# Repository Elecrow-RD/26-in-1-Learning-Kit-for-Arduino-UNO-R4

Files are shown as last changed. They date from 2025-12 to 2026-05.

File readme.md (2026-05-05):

## Menu
### 1, Product picture
### 2, Product version number
### 3, product information
### 4, Use the driver module
### 5,Quick Start
### 6,Folder structure.
### 7,Pin definition

### 1, Product picture

Crowpanel Advance ESP32 HMI AI Display

#### 2, Product version number

| | Hardware | Software | Remark |
| ---- | --- | --- | --- |
| 1 | V1.0 | V1.0 | latest |
### 3, product information

| Main Processor | Arduino UNO R4 |
| --- | --- |
| CPU/SoC | RA4M1(Arm® Cortex-M4®) |
| System memory | 32 kB SRAM |
| Storage | 256 kB Flash Memory |
| Bluetooth | Bluetooth 5 |
| Wi-Fi | Wi-Fi® support with 802.11 b/g/n standarBit rate at up to 150 Mbps2.4 GHz band |
| Interface | 6\*D Interfaces<br />4\*A Interfaces<br />4\*I2C Interfaces<br />4\* Pin header<br />2\*3pin connectors<br />1*Stepper Interface |
| Button | Reset |
| LED indicator light | 12*8 LED dot matrix |
| Power input | 5 V |
| Shell material | Plastic Box |
| Size | 278\*200*43（mm） |
| Net Weight | 600g |
| Operating temperature | 0°C to 60°C |
| Storage temperature | 0°C to 60°C |

### 4, Use the driver module

| Name | dependency library |
| --- | --- |
| IRremote | Arduino-IRremote-master <br />version: 4.5.0 |
| LSM6DS3  | Arduino_LSM6DS3-master<br />version=1.0.3 |
| BH1750 | BH1750<br />version: 1.3.0 |

### 5,Quick Start
### Arduino IDE starts

1.Download the library files used by this product to the 'libraries' folder.

C:\Users\Documents\Arduino\libraries\



2.Open the Arduino IDE and install the Uno development board.

Arduino_UNO_R4-2

3.Open the code configuration environment and burn it

Arduino_UNO_R4-4

### 6,Folder structure.

|--Eagle_SCH&PCB: Contains **Eagle CAD** schematic (`.sch`) and PCB layout (`.brd`) files. These are used for circuit design and PCB manufacturing.

|--Single Module Example:Examples of individual modules.

|--lesson_code: Provides  code and projects to demonstrate how to use the hardware and libraries. These examples help users get started quickly.

|--libraries: Includes necessary libraries required for compiling and running the project. These libraries provide drivers and additional functionalities for the hardware.

### 7,Pin definition

uno r4

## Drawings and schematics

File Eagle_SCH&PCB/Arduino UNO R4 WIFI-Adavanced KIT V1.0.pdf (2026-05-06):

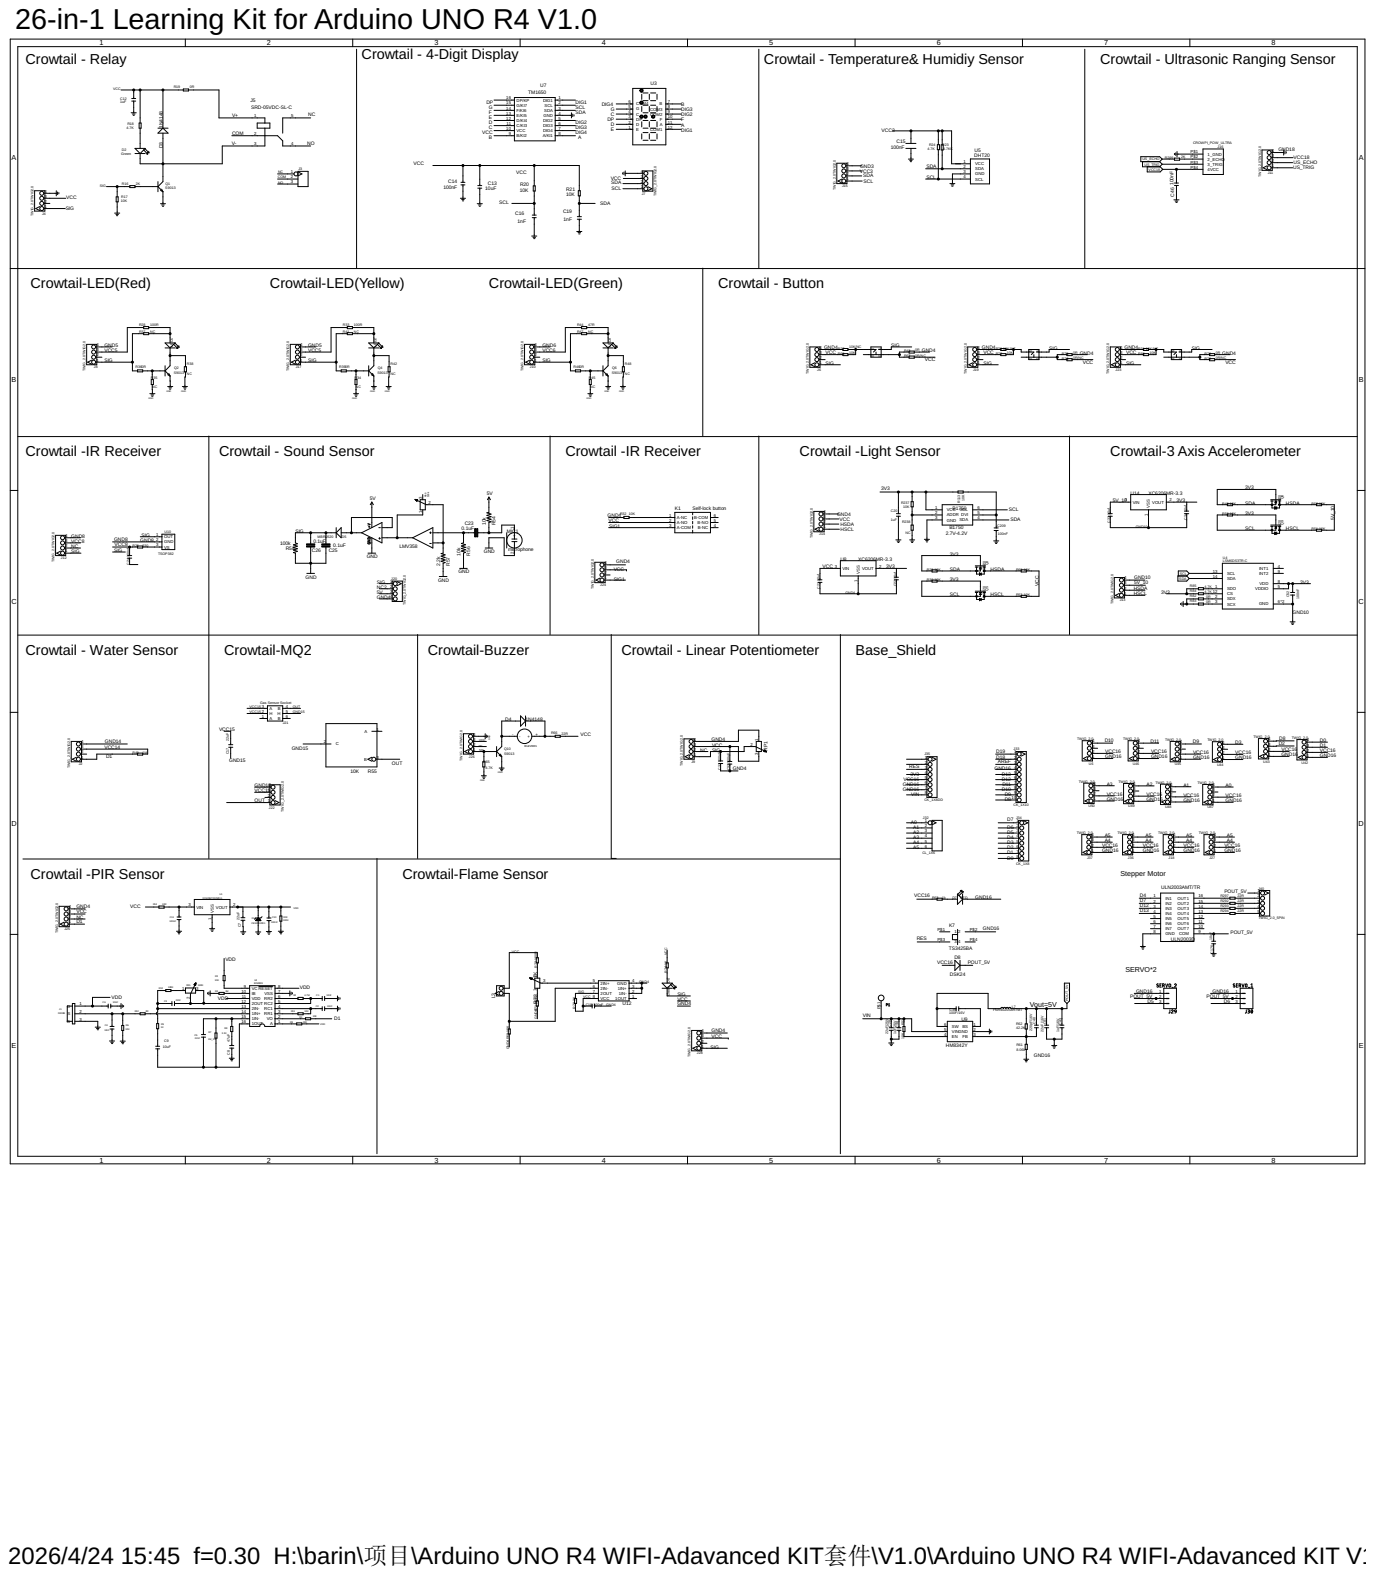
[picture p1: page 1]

Crowtail - Temperature& Humidiy Sensor

2026/4/24 15:45 f=0.30 H:\barin\项目\Arduino UNO R4 WIFI-Adavanced KIT套件\V1.0\Arduino UNO R4 WIFI-Adavanced KIT V1.0.sch (Sheet: 1/1)

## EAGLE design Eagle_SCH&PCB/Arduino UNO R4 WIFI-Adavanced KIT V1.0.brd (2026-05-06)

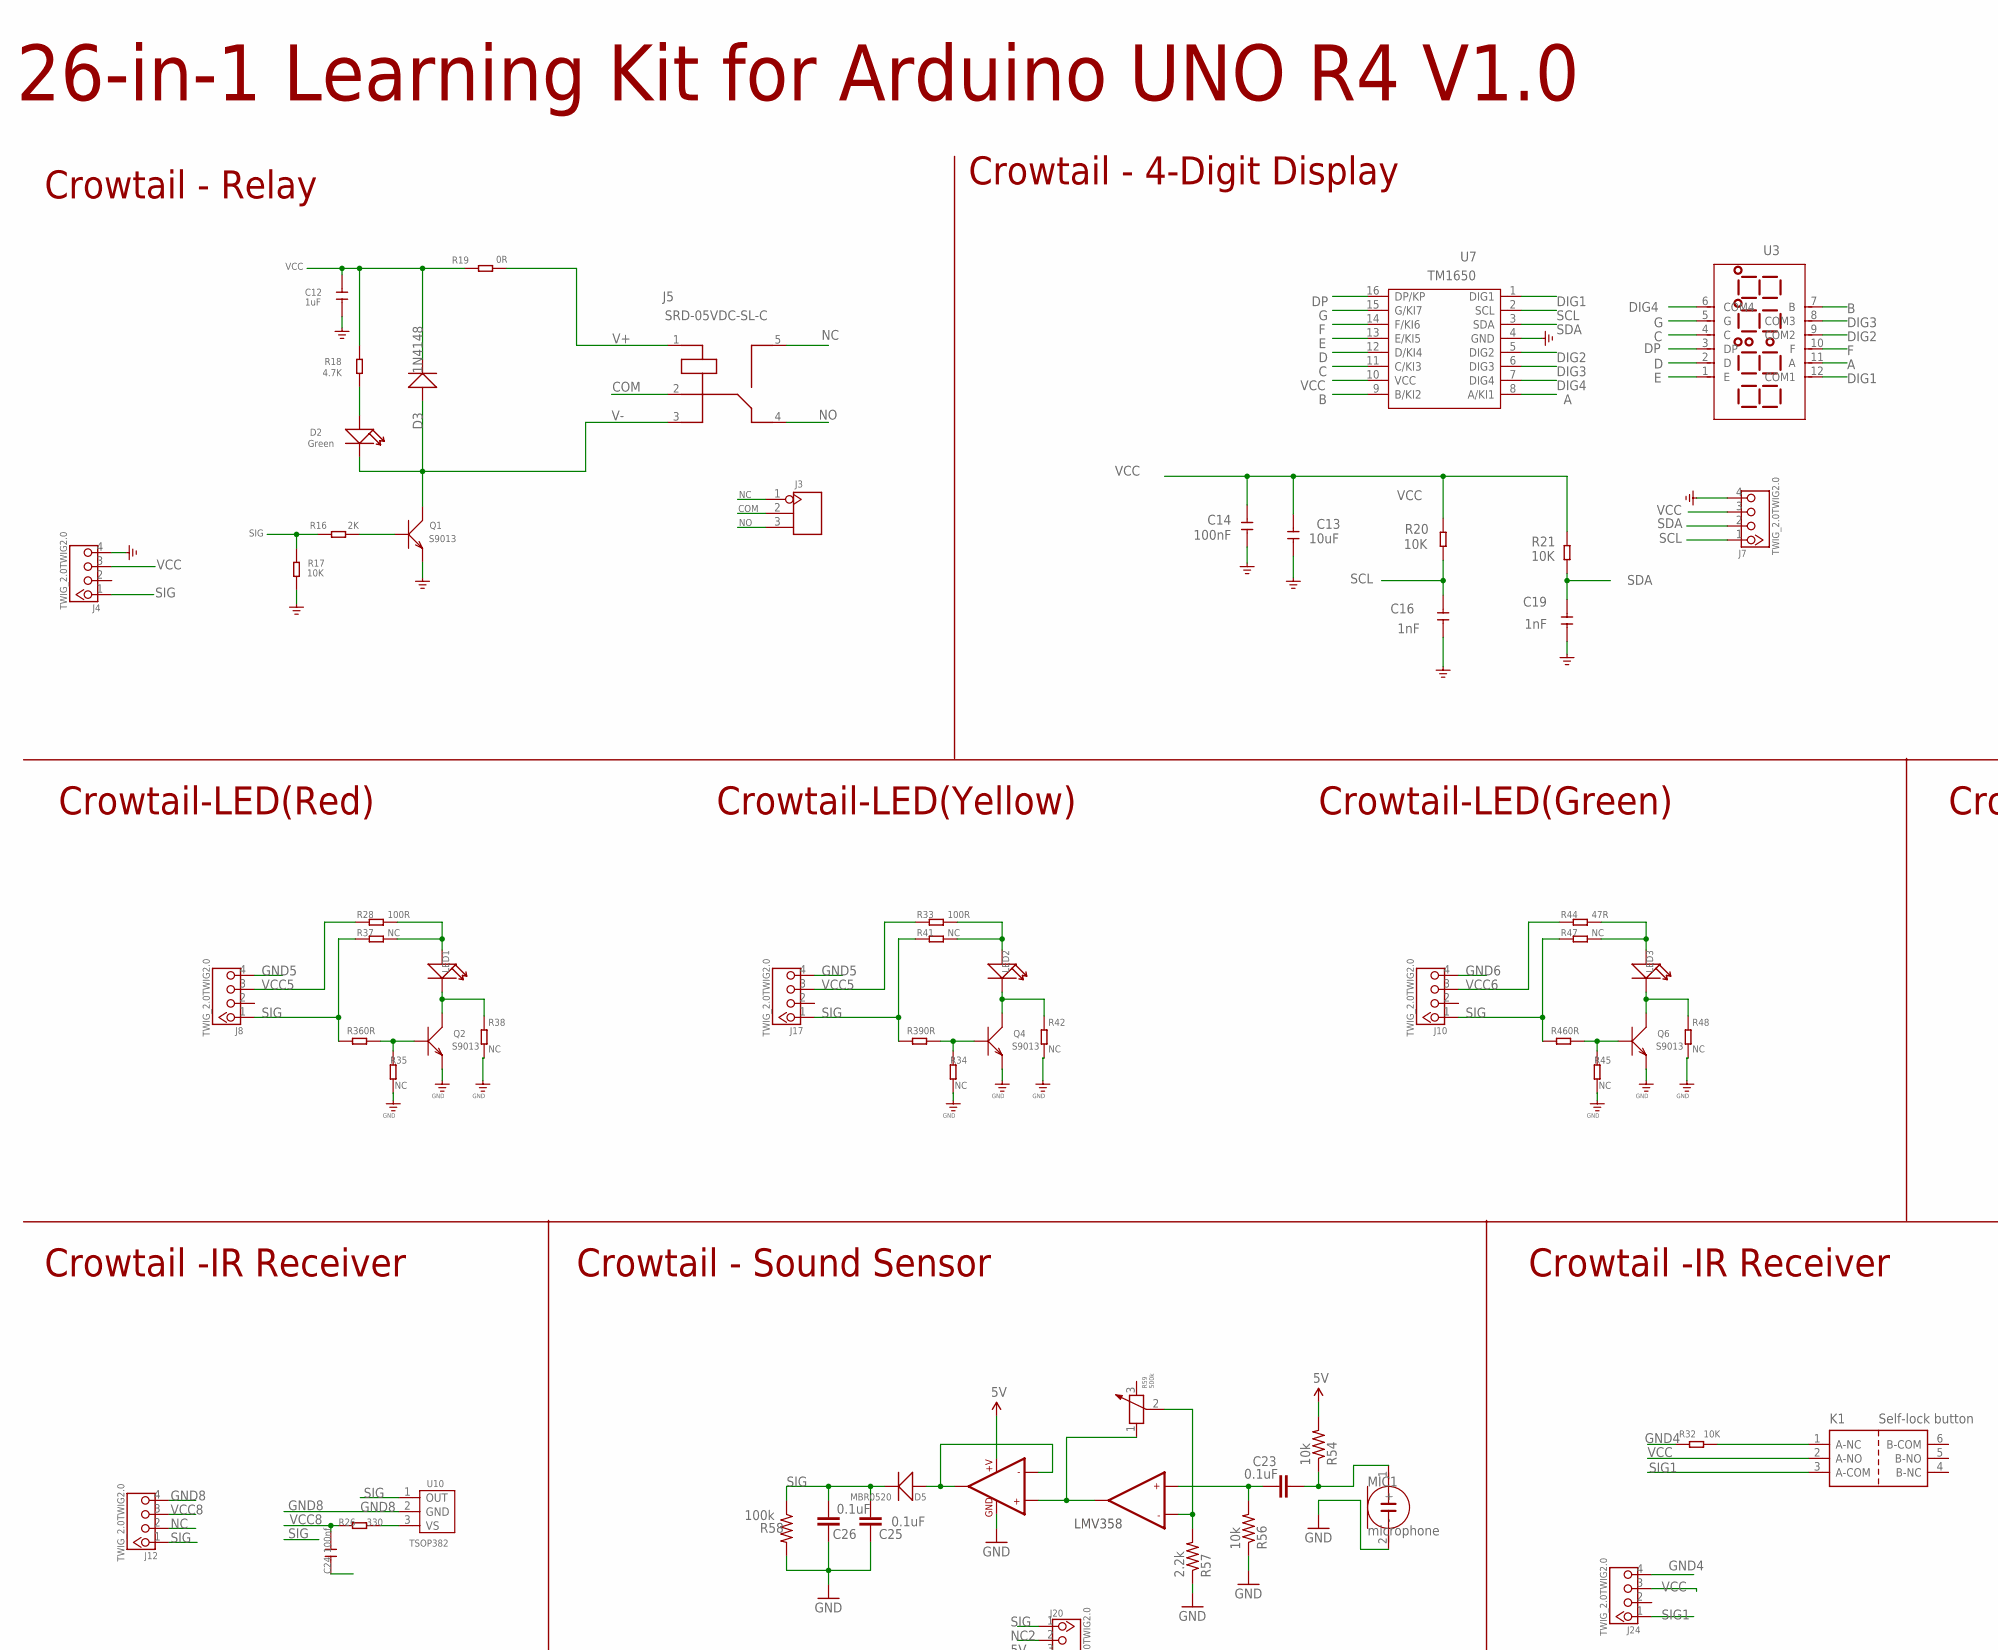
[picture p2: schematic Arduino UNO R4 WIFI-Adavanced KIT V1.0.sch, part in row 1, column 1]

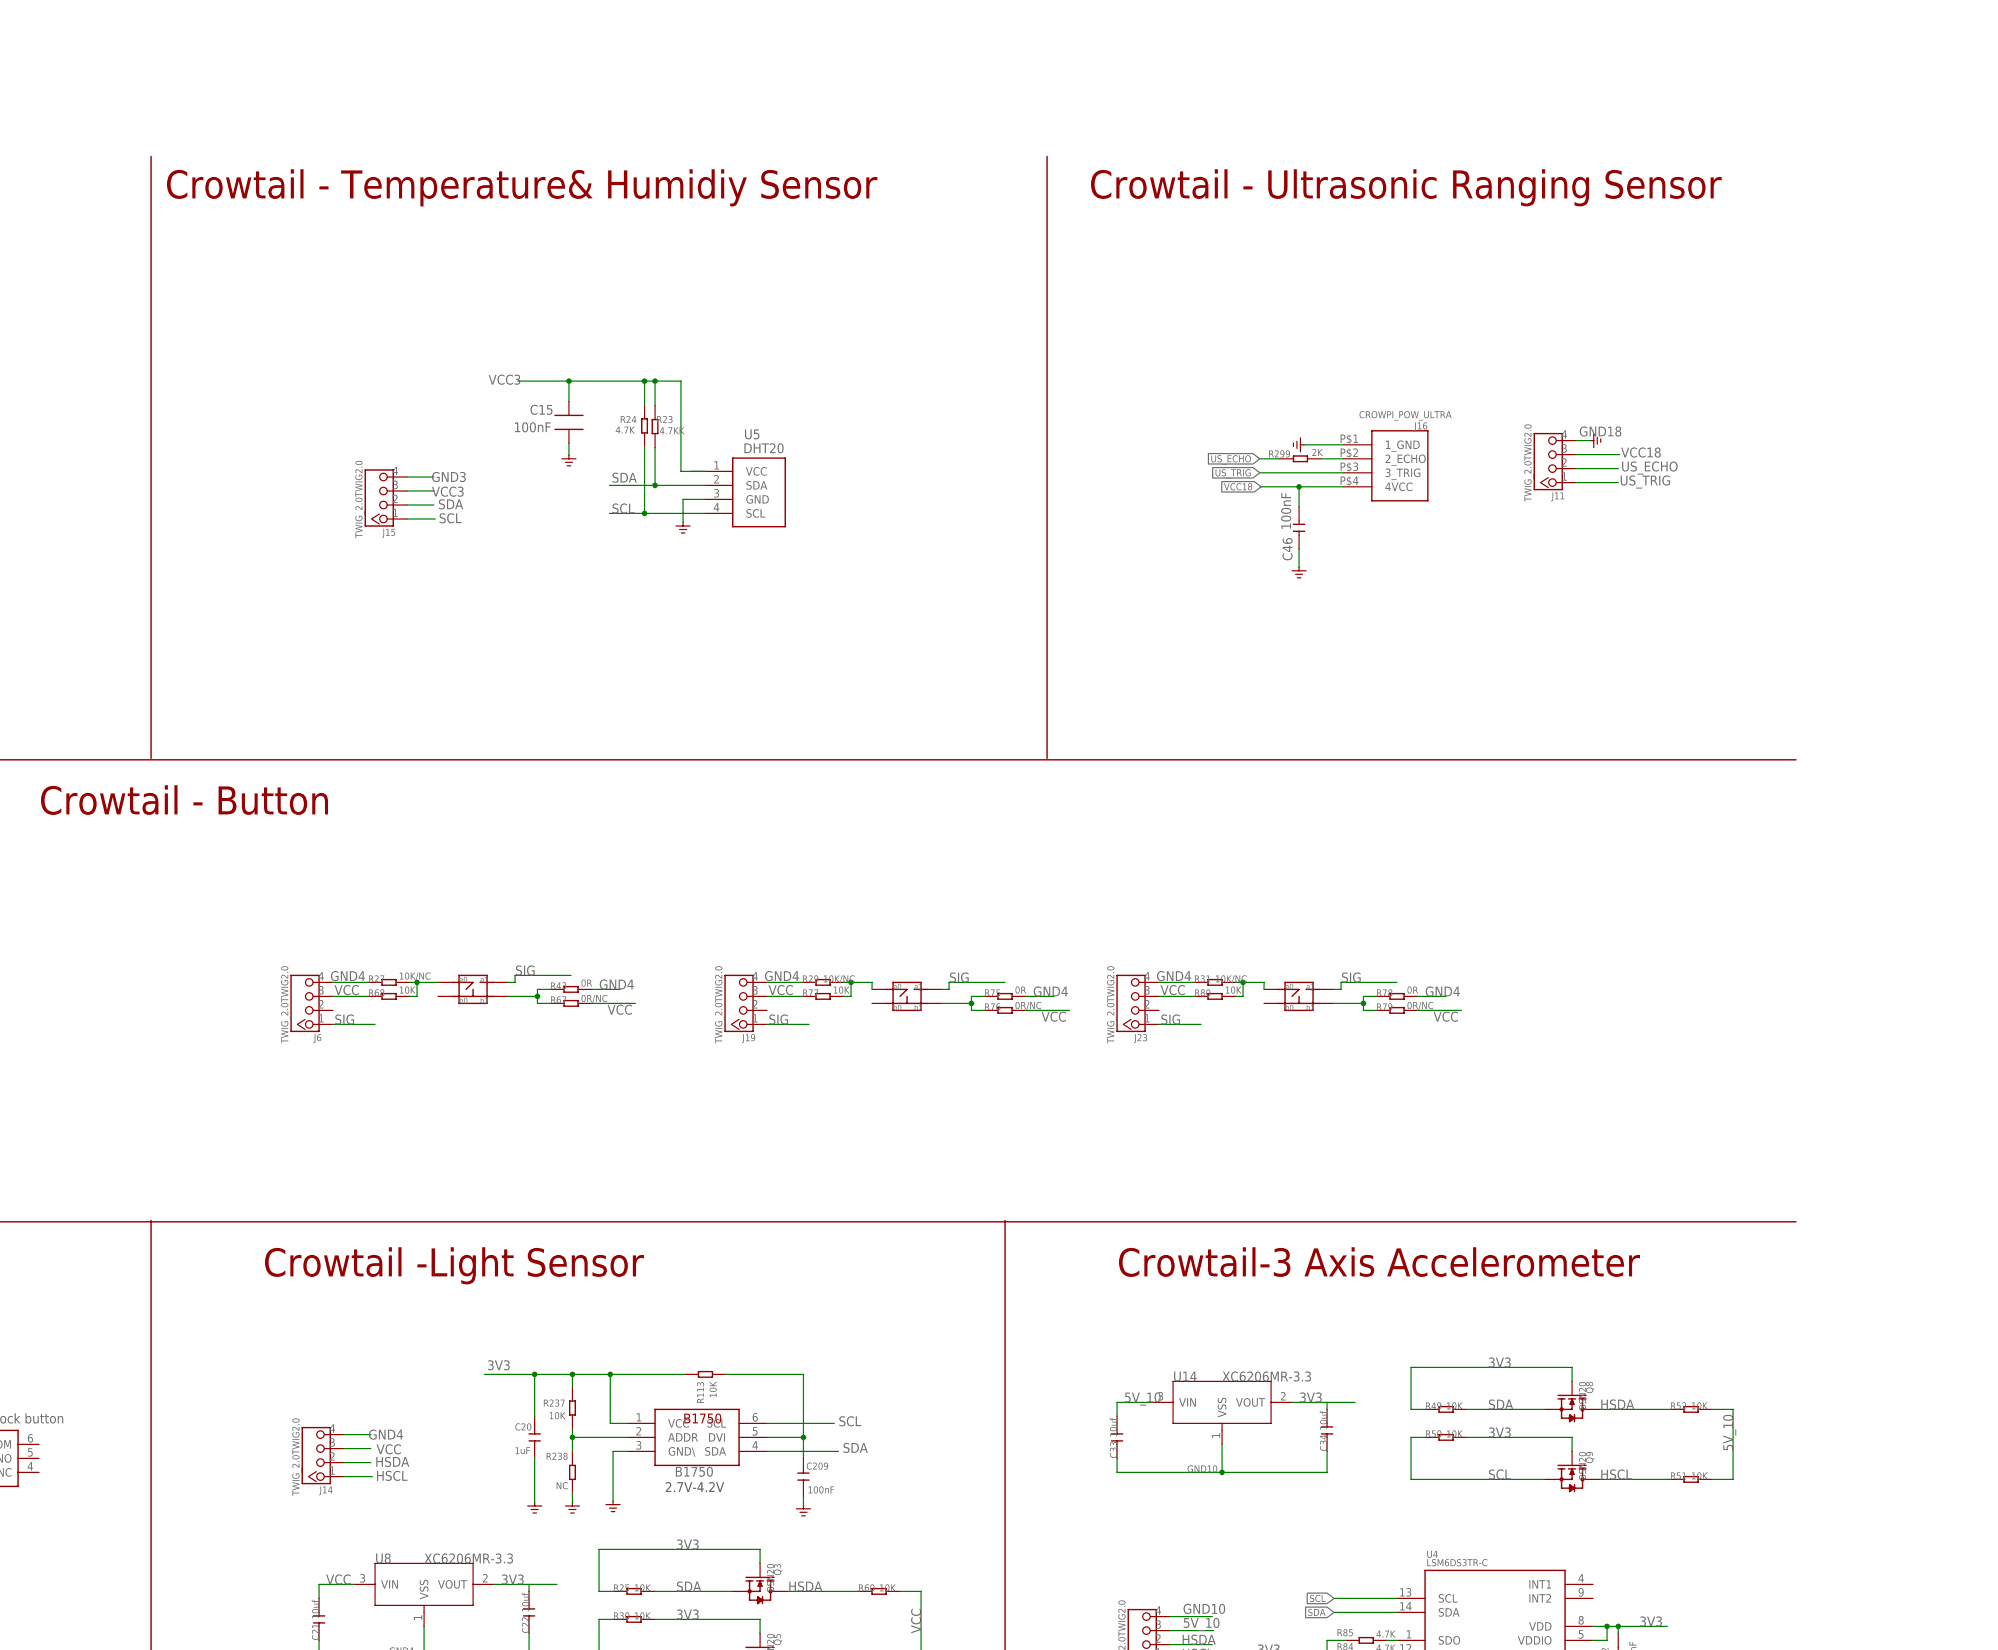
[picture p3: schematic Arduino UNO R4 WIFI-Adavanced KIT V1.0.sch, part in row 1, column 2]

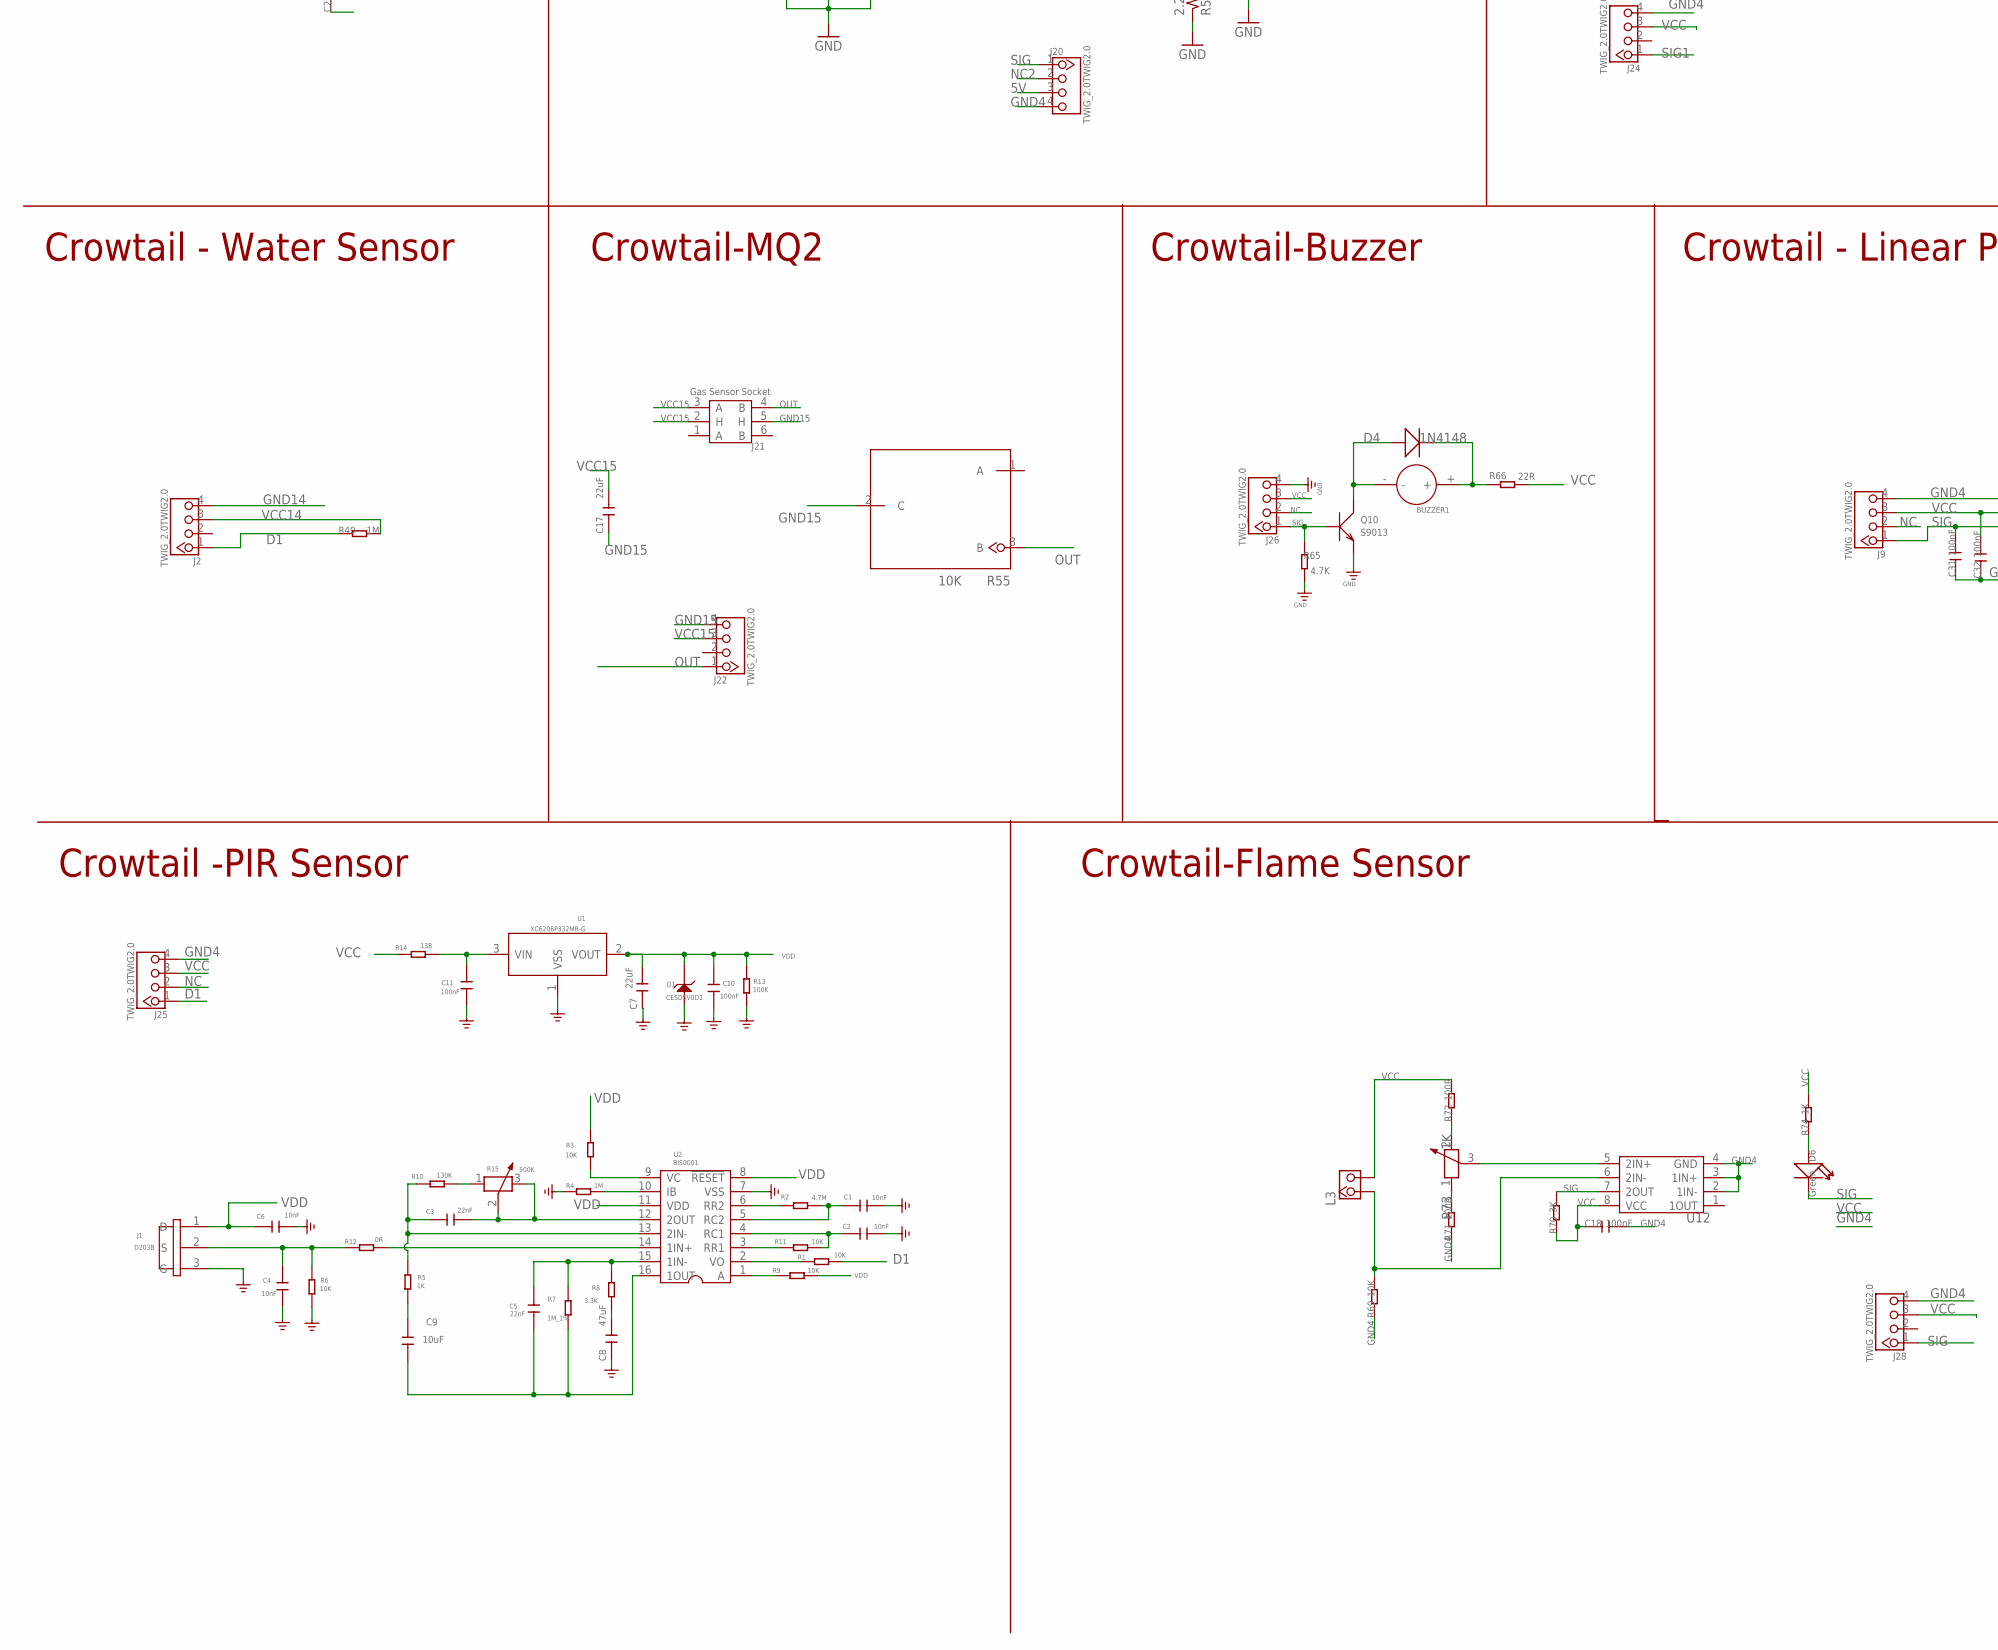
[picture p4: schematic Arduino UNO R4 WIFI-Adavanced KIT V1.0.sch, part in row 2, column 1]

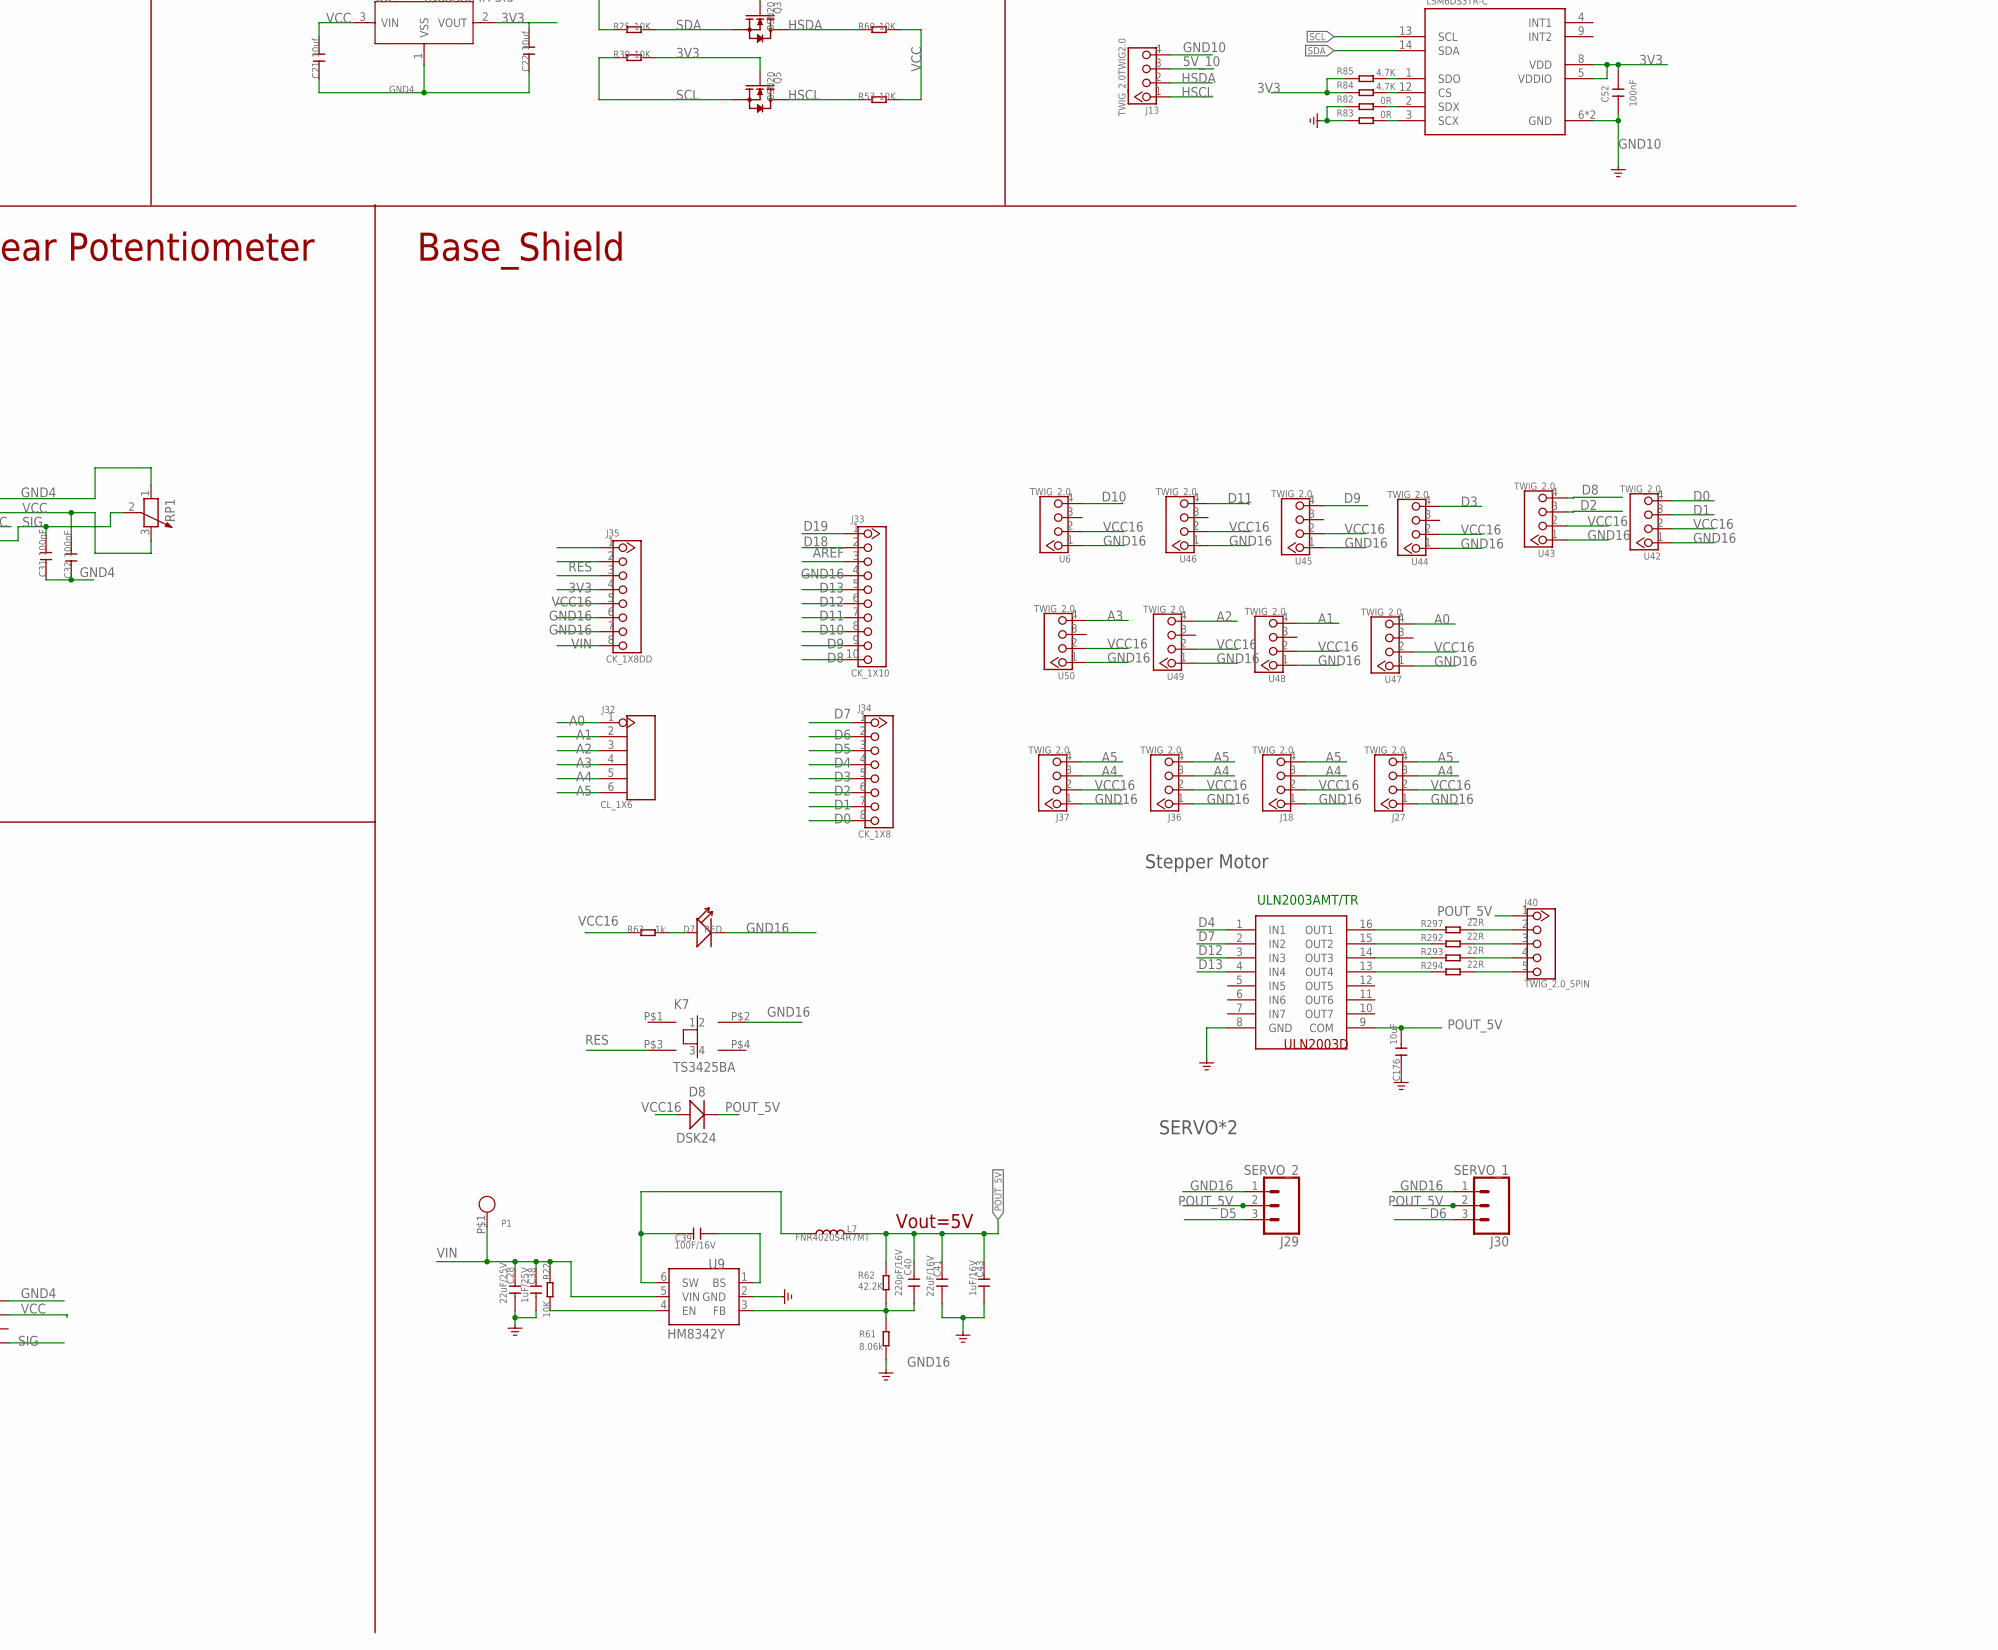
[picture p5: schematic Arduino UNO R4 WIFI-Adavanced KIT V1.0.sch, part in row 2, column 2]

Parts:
BUZZER1: BUZZER-YMD12065; 2P-7.6-D12X6.5H
C1, C2, C4, C6: 10nF; C0603
C3, C5: 22nF; C0603
C7, C17: 22uF; C0805
C8: 47uF; C0805
C9: 10uF; 0603
C10, C11, C14, C18, C31, C32, C46, C52, C209: 100nF; C0603
C12: 1uF; 0603
C13: 10uF; C0603
C15: 100nF; 0603
C16, C19: 1nF; C0603
C20: 1uF; C0603
C21, C22, C33, C34: 10uf; C0603
C23, C25, C26: 0.1uF; 0603-CAP
C24: 100nf; C0603
C28: 22uF/25V; C0805
C38: 1uF/25V; C0603
C39: 100F/16V; C0402
C40: 220pF/16V; C0402
C41: 22uF/16V; C0603
C43: 1uF/16V; C0603
C176: 10uF; C0805
D1: CESD5V0D1; SOD123-2.7X1.6@1
D2, D6: Green; LED-0603
D3, D4: 1N4148; D_SOD123
D5: MBR0520; SOD123-2.7X1.6
D7: RED; LED-0805
D8: DSK24; D_SOD123FL
J1: D203B; 3P-D8.1MM
J2, J4, J6, J7, J8, J9, J10, J11, J12, J13, J14, J15, J17, J19, J20, J22, J23, J24, J25, J26, J28: TWIG_2.0TWIG2.0; TWIG_2.0
J3: SCREW-TERMINAL-3P'5.08'; 3P-5.08
J5: SRD-05VDC-SL-C; A_XBJ_SMART_PUMP_SONGLE_RELAY
J16: CROWPI_POW_ULTRA
J18, J27, J36, J37: TWIG_2.0; 2.0_1X4
J21: Gas Sensor Socket; MQ2
J29: SERVO_2; 1X03
J30: SERVO_1; 1X03
J32: CL_1X6; CK_1X6
J33: CK_1X10
J34: CK_1X8
J35: CK_1X8DD; CK_1X8
J40: TWIG_2.0_5PIN; TWIG-2.0-5PIN
K1: Self-lock button; 6P-2CH-8X8
K2, K3, K4: 12X12
K7: TS3425BA; SMD_KEY4.2*3.*.2.5
L3: HEADER_1X2_2.54; CK_1*2
L7: FNR4020S4R7MT; L_4X4
LED1, LED2, LED3: LED-6MM; LED-2P-2.54-6MM
MIC1: microphone; 2P-D8.9MM
P1: PADPAD-1.0MM; PAD-1.0MM
Q1, Q2, Q4, Q6: S9013; SOT23@1
Q3, Q5, Q8, Q9: BSN20; SOT23@2
Q10: S9013; DISCRETE_SOT23
R1, R3, R6, R9, R11, R17, R20, R21, R25, R30, R32, R49, R50, R51, R52, R53, R60, R68, R69, R77, R80, R113, R237: 10K; R0603
R2: 4.7M; R0603
R4: 1M; R0603
R5, R74: 1K; R0603
R7: 1M_1%; R0603
R8: 3.3K; R0603
R10: 130K; R0603
R12, R19, R36, R39, R43, R46, R75, R78, R82, R83: 0R; R0603
R13: 100K; R0603
R14: 13R; R0603
R15: 500K; 3P-SMD-SQUA-3.6X3.3
R16, R299: 2K; R0603
R18, R65, R84, R85: 4.7K; R0603
R22: 10K; R0402
R23: 4.7KK; 0603
R24: 4.7K; 0603
R26: 330; R0603
R27, R29, R31: 10K/NC; R0603
R28, R33, R71, R72: 100R; R0603
R34, R35, R37, R38, R41, R42, R45, R47, R48, R238: NC; R0603
R40: 1M; 0603
R44: 47R; R0603
R54, R56: 10k; 0603-RES
R55: 10K; PACKAGE__RESISTANCE
R57: 2.2k; 0603-RES
R58: 100k; 0603-RES
R59: 500k; 3P-SMD-SQUA-3.6X3.3
R61: 8.06k; R0402
R62: 42.2K; R0402
R63: 1k; 0603
R66, R292, R293, R294, R297: 22R; R0603
R67, R76, R79: 0R/NC; R0603
R70: 3K; R0603
R73: 1K; 3P-SQUA-7X6.8
RP1: R-POTENTIOMETER; 3P-SQUA-45.6X10X5.8H
U1: XC6206P332MR-G; SOT23
U2: BIS0001; SOP16
U3: MODULE_LED-4BIT-7SEG/CLOCK; MODULE_7-4-SEG/CLOCK-2.54-32.2*10.2*5.8
U4: LSM6DS3TR-C; LGA-14L
U5: DHT20
U6, U42, U43, U44, U45, U46, U47, U48, U49, U50: TWIG_2.0; 2.0_1X4
U7: TM1650; SO16
U8, U14: XC6206MR-3.3; SOT23
U9: HM8342Y; SOT23-6L
U10: TSOP382; 3P-2.54-4.8X5X6.95H
U11: LMV358; SO08
U12: LM293D; SOIC8-6.0
U114: ULN2003AMT/TR; SOP65P640X120-16N
U121: BH1750; B1750

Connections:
3V3: C20.2, C22.2, C34.2, C52.2, J35.4, Q3.1 (G), Q5.1 (G), Q8.1 (G), Q9.1 (G), R25.1, R30.2, R49.1, R50.2, R84.1, R85.1, R113.2, R237.2, U4.5 (VDDIO), U4.8 (VDD), U8.2 (VOUT), U14.2 (VOUT), U121.1 (VCC)
5V: J20.3, R54.2, U11.8 (+V)
5V_10: C33.2, J13.3, R51.2, R52.2, U14.3 (VIN)
A: U3.11 (A), U7.8 (A/KI1)
A0: J32.1, U47.4
A1: J32.2, U48.4
A2: J32.3, U49.4
A3: J32.4, U50.4
A4: J18.3, J27.3, J32.5, J36.3, J37.3
A5: J18.4, J27.4, J32.6, J36.4, J37.4
AREF: J33.3
B: U3.7 (B), U7.9 (B/KI2)
C: U3.4 (C), U7.11 (C/KI3)
COM: J3.2, J5.2
D: U3.2 (D), U7.12 (D/KI4)
D0: J34.8, U42.4
D1: J2.1, J25.1, J34.7, R1.1, R40.1, U42.3
D2: J34.6, U43.3
D3: J34.5, U44.4
D4: J34.4, U114.1 (IN1)
D5: J29.3, J34.3
D6: J30.3, J34.2
D7: J34.1, U114.2 (IN2)
D8: J33.10, U43.4
D9: J33.9, U45.4
D10: J33.8, U6.4
D11: J33.7, U46.4
D12: J33.6, U114.3 (IN3)
D13: J33.5, U114.4 (IN4)
D18: J33.2
D19: J33.1
DIG1: U3.12 (COM1), U7.1 (DIG1)
DIG2: U3.9 (COM2), U7.5 (DIG2)
DIG3: U3.8 (COM3), U7.6 (DIG3)
DIG4: U3.6 (COM4), U7.7 (DIG4)
DP: U3.3 (DP), U7.16 (DP/KP)
E: U3.1 (E), U7.13 (E/KI5)
F: U3.10 (F), U7.14 (F/KI6)
G: U3.5 (G), U7.15 (G/KI7)
GND3: C15.2, J15.4, U5.3 (GND)
GND4: C1.2, C2.2, C4.1, C6.1, C7.1, C8.1, C10.2, C11.1, C12.1, C13.2, C14.2, C16.2, C18.2, C19.2, C20.1, C21.1, C22.1, C25.1, C26.1, C31.1, C32.1, C209.1, D1.1, J1.3 (G), J4.4, J6.4, J7.4, J9.4, J14.4, J19.4, J20.4, J23.4, J24.4, J25.4, J26.4, J28.4, MIC1.2 (-), Q1.2 (E), Q10.2 (E), R4.1, R6.1, R13.2, R17.1, R27.1, R29.1, R31.1, R32.1, R43.2, R56.1, R57.1, R58.2, R65.1, R69.1, R71.1, R75.2, R78.2, R238.1, RP1.1, U1.1 (VSS), U2.7 (VSS), U7.4 (GND), U8.1 (VSS), U11.4 (GND), U12.2 (1IN-), U12.3 (1IN+), U12.4 (GND), U121.3 (GND\)
GND5: J8.4, J17.4, Q2.2 (E), Q4.2 (E), R34.1, R35.1, R38.2, R42.2
GND6: J10.4, Q6.2 (E), R45.1, R48.2
GND8: C24.1, J12.4, U10.2 (GND)
GND10: C33.1, C34.1, C52.1, J13.4, R82.1, R83.1, U4.6 (GND), U4.7 (GND), U14.1 (VSS)
GND14: J2.4
GND15: C17.1, J21.5 (H), J22.4, R55.2 (C)
GND16: C28.1, C38.2, C41.1, C43.2, C176.2, D7.-, J18.1, J27.1, J29.1, J30.1, J33.4, J35.6, J35.7, J36.1, J37.1, K7.P$2 (2), R61.1, U6.1, U9.2 (GND), U42.1, U43.1, U44.1, U45.1, U46.1, U47.1, U48.1, U49.1, U50.1, U114.8 (GND)
GND18: C46.2, J11.4, J16.P$1 (1_GND)
HSCL: J13.1, J14.1, Q5.3 (D), Q9.3 (D), R51.1, R53.1
HSDA: J13.2, J14.2, Q3.3 (D), Q8.3 (D), R52.1, R60.1
unnamed: R82.2, U4.2 (SDX)
unnamed: R26.2, U10.3 (VS)
unnamed: C209.2, R113.1, U121.5 (DVI)
unnamed: K2.P$1, R27.2, R68.2
unnamed: Q1.1 (B), R16.2
unnamed: D2.+, R18.2
unnamed: LED2.+, R33.2, R41.1
unnamed: LED1.+, R28.2, R37.1
unnamed: LED1.-, Q2.3 (C), R38.1
unnamed: Q2.1 (B), R35.2, R36.2
unnamed: R297.1, U114.16 (OUT1)
unnamed: K4.P$1, R31.2, R80.2
unnamed: LED2.-, Q4.3 (C), R42.1
unnamed: R11.1, U2.3 (RR1)
unnamed: LED3.+, R44.2, R47.1
unnamed: C2.1, R11.2, U2.4 (RC1)
unnamed: LED3.-, Q6.3 (C), R48.1
unnamed: Q6.1 (B), R45.2, R46.2
unnamed: R1.2, U2.2 (VO)
unnamed: R2.2, U2.6 (RR2)
unnamed: C1.1, R2.1, U2.5 (RC2)
unnamed: C3.2, R15.2 (3), R15.3 (2), U2.12 (2OUT)
unnamed: C3.1, R5.2, R10.2, U2.13 (2IN-)
unnamed: R3.2, U2.9 (VC)
unnamed: R4.2, U2.10 (IB)
unnamed: C4.2, J1.2 (S), R6.2, R12.2
unnamed: C5.1, C9.2, R7.1, U2.16 (1OUT)
unnamed: C5.2, R7.2, R8.2, U2.15 (1IN-)
unnamed: C9.1, R5.1
unnamed: C8.2, R8.1
unnamed: R9.2, U2.1 (A)
unnamed: R12.1, U2.14 (1IN+)
unnamed: C11.2, R14.1, U1.3 (VIN)
unnamed: R10.1, R15.1
unnamed: Q4.1 (B), R34.2, R39.2
unnamed: K1.1 (A-NC), R32.2
unnamed: R84.2, U4.12 (CS)
unnamed: K2.P$3, R43.1, R67.1
unnamed: R292.1, U114.15 (OUT2)
unnamed: C23.1, MIC1.1 (+), R54.1
unnamed: C23.2, R56.2, U11.5 (+IN2)
unnamed: R57.2, R59.2 (3), U11.6 (-IN2)
unnamed: D5.2 (+), U11.1 (OUT1), U11.2 (-IN1)
unnamed: R59.1, U11.3 (+IN1), U11.7 (OUT2)
unnamed: R293.1, U114.14 (OUT3)
unnamed: R294.1, U114.13 (OUT4)
unnamed: D7.+, R63.2
unnamed: BUZZER1.-, D4.+, Q10.3 (C)
unnamed: BUZZER1.+, D4.-, R66.1
unnamed: R71.2, R73.1
unnamed: R83.2, U4.3 (SCX)
unnamed: R72.1, R73.2
unnamed: R73.3, U12.5 (2IN+)
unnamed: D6.+, R74.1
unnamed: L3.1, R69.2, U12.6 (2IN-)
unnamed: K3.P$1, R29.2, R77.2
unnamed: K3.P$3, R75.1, R76.1
unnamed: R85.2, U4.1 (SDO)
unnamed: R237.1, R238.2, U121.2 (ADDR)
unnamed: J40.2, R297.2
unnamed: J40.3, R292.2
unnamed: J40.4, R293.2
unnamed: J40.5, R294.2
unnamed: J16.P$2 (2_ECHO), R299.1
unnamed: R22.1, U9.4 (EN)
unnamed: C39.1, L7.1, U9.6 (SW)
unnamed: C39.2, U9.1 (BS)
unnamed: C40.1, R61.2, R62.1, U9.3 (FB)
unnamed: K4.P$3, R78.1, R79.1
NC: J3.1, J5.5, J9.2, J12.2, J25.2, J26.2
NC2: J20.2
NO: J3.3, J5.4
OUT: J21.4 (B), J22.1, R55.3 (B)
POUT_5V: C40.2, C41.2, C43.1, C176.1, D8.-, J29.2, J30.2, J40.1, L7.2, R62.2, U114.9 (COM)
RES: J35.3, K7.P$3 (3)
SCL: C16.1, J7.1, J15.1, Q5.2 (S), Q9.2 (S), R20.2, R24.1, R30.1, R50.1, U4.13 (SCL), U5.4 (SCL), U7.2 (SCL), U121.6 (SCL)
SDA: C19.1, J7.2, J15.2, Q3.2 (S), Q8.2 (S), R21.2, R23.1, R25.2, R49.2, U4.14 (SDA), U5.2 (SDA), U7.3 (SDA), U121.4 (SDA)
SIG: C25.2, C26.2, C31.2, D5.1 (-), D6.-, J4.1, J6.1, J8.1, J9.1, J10.1, J12.1, J17.1, J19.1, J20.1, J23.1, J26.1, J28.1, K2.P$2, K3.P$2, K4.P$2, Q10.1 (B), R16.1, R17.2, R36.1, R37.2, R39.1, R41.2, R46.1, R47.2, R58.1, R65.2, R70.2, RP1.2 (3), U10.1 (OUT), U12.7 (2OUT)
SIG1: J24.1, K1.3 (A-COM)
US_ECHO: J11.2, R299.2
US_TRIG: J11.1, J16.P$3 (3_TRIG)
V+: J5.1, R19.2
V-: D2.-, D3.+, J5.3, Q1.3 (C)
VCC: C12.2, C13.1, C14.1, C18.1, C21.2, C32.2, D3.-, J4.3, J6.3, J7.3, J9.3, J14.3, J19.3, J23.3, J24.3, J25.3, J26.3, J28.3, K1.2 (A-NO), L3.2, R14.2, R18.1, R19.1, R20.1, R21.1, R53.2, R60.2, R66.2, R67.2, R68.1, R70.1, R72.2, R74.2, R76.2, R77.1, R79.2, R80.1, RP1.3 (2), U7.10 (VCC), U8.3 (VIN), U12.8 (VCC)
VCC3: C15.1, J15.3, R23.2, R24.2, U5.1 (VCC)
VCC5: J8.3, J17.3, R28.1, R33.1
VCC6: J10.3, R44.1
VCC8: C24.2, J12.3, R26.1
VCC14: J2.3, R40.2
VCC15: C17.2, J21.2 (H), J21.3 (A), J22.3
VCC16: D8.+, J18.2, J27.2, J35.5, J36.2, J37.2, R63.1, U6.2, U42.2, U43.2, U44.2, U45.2, U46.2, U47.2, U48.2, U49.2, U50.2
VCC18: C46.1, J11.3, J16.P$4 (4VCC)
VDD: C6.2, C7.2, C10.1, D1.2, J1.1 (D), R3.1, R9.1, R13.1, U1.2 (VOUT), U2.8 (!RESET), U2.11 (VDD)
VIN: C28.2, C38.1, J35.8, P1.P$1, R22.2, U9.5 (VIN)

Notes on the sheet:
Crowtail -PIR Sensor
Crowtail - Temperature& Humidiy Sensor
Crowtail-LED(Red)
Crowtail -IR Receiver
Crowtail-3 Axis Accelerometer
Crowtail - Water Sensor
Crowtail-MQ2
Crowtail - Ultrasonic Ranging Sensor
LMV358
2.7V-4.2V
Stepper Motor
ULN2003AMT/TR
SERVO*2
Crowtail - Relay
Crowtail - 4-Digit Display
Crowtail-LED(Yellow)
Crowtail-LED(Green)
Crowtail - Button
Crowtail - Sound Sensor
Crowtail -Light Sensor
Crowtail-Flame Sensor
Crowtail-Buzzer
Crowtail - Linear Potentiometer
Base_Shield
Vout=5V
26-in-1 Learning Kit for Arduino UNO R4 V1.0

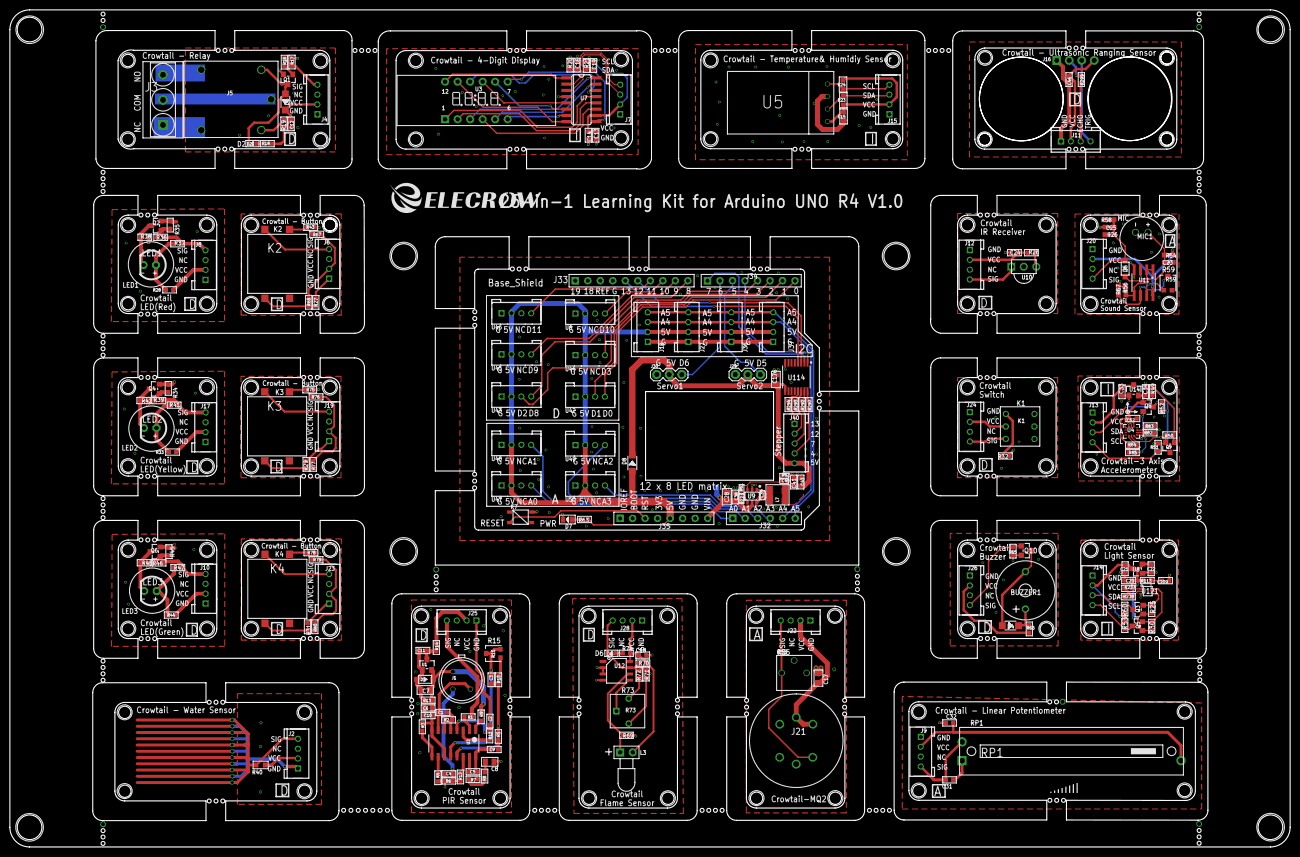
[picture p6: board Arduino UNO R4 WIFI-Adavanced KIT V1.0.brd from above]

Board: 2 copper layers, 260.0 x 170.0 mm, 223 parts (1 on the bottom side), 140 nets.

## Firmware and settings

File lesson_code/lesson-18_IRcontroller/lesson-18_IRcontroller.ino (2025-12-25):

/*
  IR Remote + LED Control
  Button 1: Red light on
  Button 2: Yellow light on
  Button 3: Green light on
  Button 4: Three lights in sequence (cyclic)
*/

#include <DIYables_IRcontroller.h> 

#define IR_RECEIVER_PIN 3

DIYables_IRcontroller_21 irController(IR_RECEIVER_PIN, 200);

// LED pin
#define LED_RED 11
#define LED_YELLOW 10
#define LED_GREEN 9

int mode = 0;  // Current working mode: 1 = Red light / 2 = Yellow light / 3 = Green light / 4 = Continuous flow

void setup() {
  Serial.begin(115200);
  irController.begin();

  pinMode(LED_RED, OUTPUT);
  pinMode(LED_YELLOW, OUTPUT);
  pinMode(LED_GREEN, OUTPUT);
}

// Encapsulate a function: Clear all lights
void allOff() {
  digitalWrite(LED_RED, LOW);
  digitalWrite(LED_YELLOW, LOW);
  digitalWrite(LED_GREEN, LOW);
}

void loop() {

  // ---- Read infrared key value ----
  Key21 command = irController.getKey();
  if (command != Key21::NONE) {
    switch (command) {

      case Key21::KEY_CH_MINUS:
        Serial.println("CH-");
        // TODO: YOUR CONTROL
        break;

      case Key21::KEY_CH:
        Serial.println("CH");
        // TODO: YOUR CONTROL
        break;

      case Key21::KEY_CH_PLUS:
        Serial.println("CH+");
        // TODO: YOUR CONTROL
        break;

      case Key21::KEY_PREV:
        Serial.println("<<");
        // TODO: YOUR CONTROL
        break;

      case Key21::KEY_NEXT:
        Serial.println(">>");
        // TODO: YOUR CONTROL
        break;

      case Key21::KEY_PLAY_PAUSE:
        Serial.println(">||");
        // TODO: YOUR CONTROL
        break;

      case Key21::KEY_VOL_MINUS:
        Serial.println("–");
        // TODO: YOUR CONTROL
        break;

      case Key21::KEY_VOL_PLUS:
        Serial.println("+");
        // TODO: YOUR CONTROL
        break;

      case Key21::KEY_EQ:
        Serial.println("EQ");
        // TODO: YOUR CONTROL
        break;

      case Key21::KEY_100_PLUS:
        Serial.println("100+");
        // TODO: YOUR CONTROL
        break;

      case Key21::KEY_200_PLUS:
        Serial.println("200+");
        // TODO: YOUR CONTROL
        break;

      case Key21::KEY_0:
        Serial.println("Turn off all the lights");
        mode = 0;
        // TODO: YOUR CONTROL
        break;

      case Key21::KEY_1:  //Button 1
        Serial.println("Mode 1: The red light is on");
        mode = 1;
        break;

      case Key21::KEY_2:  // Button 2
        Serial.println("Mode 2: The yellow light is on");
        mode = 2;
        break;

      case Key21::KEY_3:  // Button 3
        Serial.println("Mode 3: The green light is on");
        mode = 3;
        break;

      case Key21::KEY_4:  // Button 4
        Serial.println("Mode 4: Three lamps and flowing water");
        mode = 4;
        break;

      case Key21::KEY_5:
        Serial.println("5");
        // TODO: YOUR CONTROL
        break;

      case Key21::KEY_6:
        Serial.println("6");
        // TODO: YOUR CONTROL
        break;

      case Key21::KEY_7:
        Serial.println("7");
        // TODO: YOUR CONTROL
        break;

      case Key21::KEY_8:
        Serial.println("8");
        // TODO: YOUR CONTROL
        break;

      case Key21::KEY_9:
        Serial.println("9");
        // TODO: YOUR CONTROL
        break;

      default:
        Serial.println("WARNING: undefined command:");
        break;
    }
  }

  // ---- Perform the action according to the mode. ----
  switch (mode) {
    case 0:
      allOff();
      break;

    case 1: // The red light is on
      allOff();
      digitalWrite(LED_RED, HIGH);
      break;

    case 2: // The yellow light is on
      allOff();
      digitalWrite(LED_YELLOW, HIGH);
      break;

    case 3: // The green light is on
      allOff();
      digitalWrite(LED_GREEN, HIGH);
      break;

    case 4: // waterfall light
      allOff();
      digitalWrite(LED_RED, HIGH);
      delay(300);

      allOff();
      digitalWrite(LED_YELLOW, HIGH);
      delay(300);

      allOff();
      digitalWrite(LED_GREEN, HIGH);
      delay(300);
      break;

    default:
      // Initial state: All off
      allOff();
      break;
  }
}

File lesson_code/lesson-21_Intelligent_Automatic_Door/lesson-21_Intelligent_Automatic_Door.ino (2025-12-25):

#include <HCSR04.h>
#include <Servo.h>

/* ---------- Ultrasonic ---------- */
const byte triggerPin = 8;
const byte echoPin = 2;
UltraSonicDistanceSensor distanceSensor(triggerPin, echoPin);

/* ---------- Servo ---------- */
#define SERVO1_PIN 6

Servo myservo1;

int doorOpenAngle = 90;    // Door open angle (adjustable)
int doorCloseAngle = 0;    // Door close angle

/* ---------- Buzzer ---------- */
#define BUZ 10

/* ---------- State variables ---------- */
bool doorIsOpen = false;          // Current door state
unsigned long lastDetectTime = 0; // Last time a person was detected
const unsigned long closeDelay = 5000; // 5 seconds

void setup() {
  Serial.begin(115200);

  myservo1.attach(SERVO1_PIN, 600, 2520);

  pinMode(BUZ, OUTPUT);

  // Initial state: door closed
  myservo1.write(doorCloseAngle);
}

void loop() {

  /* ---------- 1. Read distance ---------- */
  float distance = distanceSensor.measureDistanceCm();
  if (distance < 0) 
    return;

  Serial.print("Distance: ");
  Serial.print((int)distance);
  Serial.println(" cm");

  /* ---------- 2. Anti-pinch alarm ---------- */
  if (distance > 0 && distance <= 10) {
    buzzerWarning();
  }

  /* ---------- 3. Door opening logic ---------- */
  if (distance > 0 && distance <= 50) {
    openDoor();
    lastDetectTime = millis(); // Record the time when a person is detected
  }

  /* ---------- 4. Door closing logic ---------- */
  if (doorIsOpen) {
    if (millis() - lastDetectTime >= closeDelay) {
      closeDoor();
    }
  }

  delay(200);
}

/* ================== Function definitions ================== */

// Open the door
void openDoor() {
  if (!doorIsOpen) {
    myservo1.write(doorOpenAngle);
    doorIsOpen = true;
    Serial.println("Door OPEN");
  }
}

// Close the door
void closeDoor() {
  myservo1.write(doorCloseAngle);
  doorIsOpen = false;
  Serial.println("Door CLOSE");
}

// Buzzer warning (two beeps)
void buzzerWarning() {
  for (int i = 0; i < 2; i++) {
    digitalWrite(BUZ, HIGH);
    delay(150);
    digitalWrite(BUZ, LOW);
    delay(150);
  }
}

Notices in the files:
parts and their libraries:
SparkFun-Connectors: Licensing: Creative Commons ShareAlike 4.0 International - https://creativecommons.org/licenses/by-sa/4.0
